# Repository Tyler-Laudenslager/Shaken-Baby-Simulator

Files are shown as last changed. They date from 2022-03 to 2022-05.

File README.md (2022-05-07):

<h1>St. Lukes Simulation Center / The Cauldron</h1>





<h2>Shaken Baby Simulator Project</h2>

<p>.fzz files are from https://fritzing.org/
<br>
.xlsx files are normal Microsoft Excel files
<br>
https://circuitpython.org/
<br>
https://learn.adafruit.com/
<br>
https://codewith.mu/en/
</p>
<br>
<br>
<p>There are no <b>malicious<b> files in this repo!!</p>

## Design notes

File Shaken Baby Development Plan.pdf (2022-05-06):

# Shaken Baby Simulator Software Development Plan & Requirements

March 1, 2022

Version 1.1

Presented To:

St. Luke's Network Simulation Center 3D Print & Innovation Lab

Submitted By:
Tyler Laudenslager, Boyd Lenich, and Andrew Sheidy

### REVISION HISTORY

Date | Author | Distributed to | Version | Description
February 27th | | | 1.0 | Draft
March 1st | Tyler L. | N?A | 1.1 | Added more info to Use Cases, Non Functional Requirements, ,Research Sections, and Project Organization sections.
4/10/2022 | Tyler L. | N?A | 1.2 | Added the prototype architecture pictures to the respective section.

REVISION HISTORY | 2
1. PRODUCT DESCRIPTION | 4
2. PRODUCT REQUIREMENTS | 4
Context Diagram | 4
Personas | 5
User Stories | 5
High Level Use Cases | 6
Use Case Descriptions | 6
3. USER EXPERIENCE WIREFRAMES | 9
4. NON FUNCTIONAL REQUIREMENTS | 9
Other Systems | 9
Security | 10
Performance | 10
Maintainability | 10
Budget | 10
5. PROJECT ORGANIZATION - | 12
Matrix of Responsibilities / Skills | 12
PERT / Gantt Chart | 13
6. VALIDATION PLAN | 13
Test Strategy | 13
7. RISK MANAGEMENT PLAN | 14
Research | 14
Baby Research - Need to Do | 14
Hardware / Software Research | 14
Risk Identification | 17
Risk Prioritization | 17
Risk Mitigation | 17
8. CONFIGURATION AND VERSION CONTROL | 18
9. TOOLS | 18
10. ARCHITECTURE | 19
11. RELATED LINKS | 19

### 1. PRODUCT DESCRIPTION

We are solving an issue with child care, specifically for guardians who are new to interacting with an infant. The idea is to have a doll that responds to how it is treated to show signs of shaken baby syndrome, an issue that can happen if improper care is given while holding an infant. The doll will give info, to tell the handler that they are handling the baby correctly, or if they are giving the doll too much motion, and it will respond with information on a screen, as well as with qualitative changes, such as sound, and color.

### 2. PRODUCT REQUIREMENTS

Describe the users and user environment.

### Context Diagram

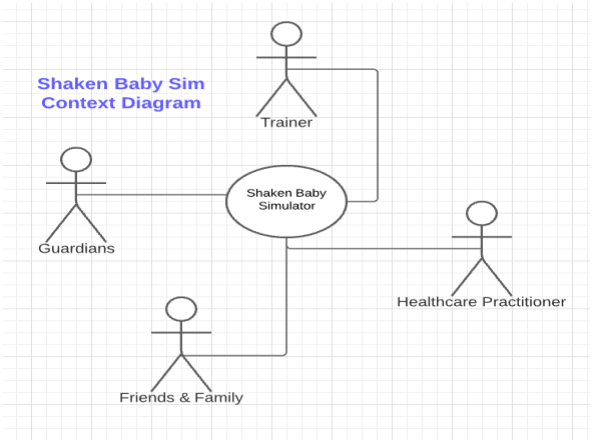
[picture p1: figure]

### Personas

Healthcare practitioner - Someone who would want to use to learn about child handling in a healthcare sense rather than a guardian sense

Family and Friends - Connected to the guardian, but does not need as in depth coaching on child handling as they would not have as close proximity

Guardians - Wants an in depth look on how to handle a child safely

Educator / Trainer - Someone who is using the doll as a teaching tool for others

### User Stories

- Healthcare Practitioner
- As a nurse, I want accurate data representation so I can know more

about child handling at a more detailed level, so I can have more

knowledge when handling a child.

- Family and Friends of the Baby
- Being a friend to new parents I would like to be less anxious about

holding a child for the first time and to assure my new parent friends

that I can hold a child properly to have them feel less anxious about

me holding their child. Some of the fears I have is not properly

supporting a child when holding it or some of the dangers that could

be present that I am unaware of when holding the baby.

- As a grandparent I would like to show my competency in holding a

baby to my children, so they feel less anxious about me handling

fragile packaging.

- As a six-year-old I would like to show everyone that I am capable of

important things such as being able to properly show I am all grown

up to handle a baby now.

- I am a babysitter who would like to train other babysitters how to

properly hold a baby to provide confidence to them and the parents

of the baby before they need to watch the baby.

- Guardians of the Baby
- As a parent, I want to know more about child handling, and how safe

I need to be when handling them so that I can be a better parent.

- As a parent, I want my older children to be able to understand how

fragile a child is so they can safely interact with their new siblings.

- Educator / Trainer
- As an Educator / Trainer, I want to teach parents about child handling

in a way that gives them more information and experience, so that I

can do my job more efficiently and train them better.

### High Level Use Cases

Rotate Baby - rotating the baby in various horizontal and vertical positions.

Shake Baby - shaking the baby gently, moderately, and violently.

Drop Baby - dropping the baby from various heights.

Read Condition - read the condition of the baby (good/dangerous/bad).

### Use Case Descriptions

1. Name: Rotate Baby
2. Participating Actors: Healthcare Practitioner, Trainer, Baby Handler..

3. Entry Condition: Charged Battery.
4. Exit Condition: Baby Makes Sound.
5. Flow of Events:
a. Pick up baby sim.
b. Rotate baby sim.
c. Emit sound/no sound from baby.
6. Special Requirements:
a. If the baby is upside down, have the baby cry until the baby is upright.

—---------------------------------------------------------------------------------------------------

1. Name: Shake Baby
2. Participating Actors: Healthcare Practitioner, Trainer, Baby Handler
3. Entry Condition: Charged Battery
4. Exit Condition: Baby Displays Light from LEDs
5. Flow of Events:
a. Pick up baby sim
b. Shake baby sim
c. Emit light from LEDs
6. Special Requirements:
a. If the baby is shaken at max force level, display red
b. If the baby is shaken at moderate force level, display yellow
c. If the baby is shaken at gentle force level, display green.

—---------------------------------------------------------------------------------------------------

1. Name: Drop Baby
2. Participating Actors: Healthcare Practitioner, Trainer, Guardian, Baby Handler.
3. Entry Condition: Charged Battery.
4. Exit Condition: Baby Cries and Displays Light from LEDs.
5. Flow of Events:
a. Pick up baby sim.
b. Drop baby sim from a relative height.
c. Emit sound.
d. Emit light.
6. Special Requirements:
a. If time to fall is below a half a second display yellow.
b. If time to fall is above half a second display red.

—---------------------------------------------------------------------------------------------------

1. Name: Read Condition
2. Participating Actors: Healthcare Practitioner, Trainer, Baby Handler
3. Entry Condition: Charged Battery and (Shake or Drop or Rotate event)
4. Exit Condition: Condition Understood
5. Flow of Events:
a. Perform either a Rotate or Drop or Shake operation on the baby sim

b. Read the condition
c. Reference the User Manual
d. Understand the condition

### 3. USER EXPERIENCE WIREFRAMES

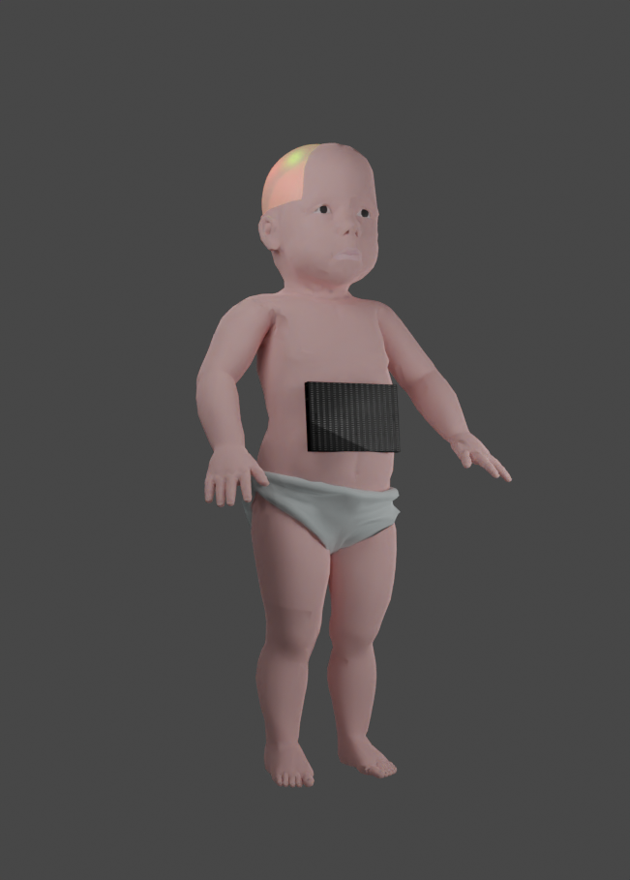
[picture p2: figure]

### 4. NON FUNCTIONAL REQUIREMENTS Other Systems

What other systems to interface with? Dependent on?.

The system is self contained and does not depend on outside systems to operate with full usability.

### Security

There will be an emphasis on protecting end users from any damage that can occur when dealing with any lithium-ion battery packs. There will also be considerations to dealing with making it difficult to accidentally be in direct contact with the system itself. We will provide this functionality by encasing the system within the baby itself.

### Performance

Up time - We are planning on having the system be up and fully usable only when required to be and off when necessary.

Response time? - The response time of the system should be near real time responsiveness with a plus / minus a half second delay.

### Maintainability

How will it be maintained? - The system will be maintained remotely when necessary to incorporate other features requested by the customer using a version control system such as Github with full documentation to provide full disclosure of the changes made to the system over time for the customer and users alike.

### Budget

## Shaken Baby Simulator Prototype Shopping List

Product Page | Description | Price (in dollars $) | Quantit y to Purcha se
https://www.adafruit.com/product/2809 (https://www.adafruit.com/product/2809) | Adafruit LIS3DH Triple-Axis Accelerometer (+-2g/4g/8g/16g) | $4.95 | 1
https://www.adafruit.com/product/4884 (https://www.adafruit.com/product/4884) | Black Adafruit Feather RP2040 | $11.95 | 1
https://www.adafrui (https://www.adafruit.com/product/4864) | Raspberry Pi Pico RP2040 | $4.00 | 1

t.com/product/4864 (https://www.adafruit.com/product/4864)

https://www.adafruit.com/product/2671 (https://www.adafruit.com/product/2671) | 2mm Pitch 40-Pin Break-apart Male Headers -Pack of 5 | $2.95 | 1
https://www.adafruit.com/product/159 (https://www.adafruit.com/product/159) | Diffused RGB (tri-color) LED - Common Anode | $6.00 | 3
https://www.adafruit.com/product/3006 (https://www.adafruit.com/product/3006) | Adafruit I2S 3W Class D Amplifier Breakout -MAX98357A | $5.95 | 1
https://www.adafruit.com/product/3968 (https://www.adafruit.com/product/3968) | Speaker - 40mm Diameter -4 Ohm 3 Watt | $4.95 | 1
https://www.adafruit.com/product/258 (https://www.adafruit.com/product/258) | Lithium Ion Polymer Battery - 3.7v 1200mAh | $9.95 | 1
https://www.adafruit.com/product/1954 (https://www.adafruit.com/product/1954) | Premium Female/Male 'Extension' Jumper Wires -20 x 6" | $1.95 | 1
https://www.adafruit.com/product/902 (https://www.adafruit.com/product/902) | Adafruit Bicolor LED Square Pixel Matrix with I2C Backpack | $15.95
| Price Total | $68.60
| Optional Choices | | 1
https://www.adafruit.com/product/2738 (https://www.adafruit.com/product/2738) | Raspberry Pi Sense HAT -any Raspberry Pi with 2x20 Connector | $39.95

*Some products may be discontinued and / or unavailable due to supply shortages / demand.

**Prices subject to change.

### 5. PROJECT ORGANIZATION -

Breakdown of major tasks and schedule

Key

NC - Not Comfortable

C - Comfortable

P - Partial Experience

### Matrix of Responsibilities / Skills

Skills Needed | Skills Acquired
| Drew S. | Boyd L. | Tyler L.
Circuit Python | NC
Github / Git | P | P | P
User Interface | P | | P
Product Design | P | | P
Baby Research | P | P
Knowledge of Microcontrollers | NC
Knowledge of Accelerometers | NC
Knowledge of Speakers | NC
Two-Dimensional Array Programming | NC | P | P
Debugging / Troubleshooting | P P

Skills Needed | Skills Acquired
Testing | P | P
Responsibilities | Drew S. | Boyd L. | Tyler L.
Testing | P
Anatomical Research | NC | X
LED Matrix Programming | NC | | X
Accelerometer Programming | NC | X | X
Hardware Research | P X
User Interface Design | p | x
Circuitry Design | NC | | X

### PERT / Gantt Chart

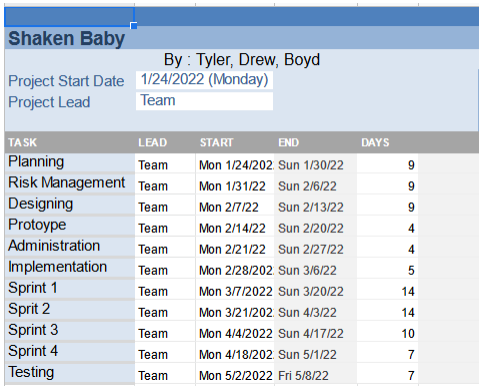
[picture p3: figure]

### 6. VALIDATION PLAN

### Test Strategy

What is the definition of done?

The definition of done is defined as all components have been integrated together within the system and the system has been fully tested for each expected input output of every use case.

What does success look like?

Success is the measure of how effectively we convey to the user of the system how to properly handle a baby given the force applied in various situations using clearly defined indicators built into the system.

If the user can instantly tell when they have applied too much force to the baby in any given situation this is how we will know we have achieved success.

### 7. RISK MANAGEMENT PLAN

What are the known risks and how will they be handled?

### Research

Hardware / Software Research

In this part we are going to discuss all the hardware decisions as related to the design of the shaken baby simulator. We will discuss the differences between a microcontroller versus a micro-computer. After a brief discussion we will discuss all the major components of the system and why we decided to choose some components over others. We will conclude with a brief discussion of the software that is needed to control the hardware of the system.

Microcontroller Vs. Micro-Computer:

There is a distinct reason we used a Micro-Controller such as an Arduino versus a Micro-Computer such as a Raspberry Pi in this implementation of the system. A Micro-Controller has a dedicated program that runs in a loop that provides a specific functionality and is very suitable for connecting various components such as temperature, acceleration and light sensors and emitters. A Micro-Computer is more for variable uses across a variety of different applications depending on the needs of the user at a particular time.

With the previous discussion in mind therefore we decided to choose a Microcontroller instead of a Micro-Computer for the project implementation. The specific Micro-Controller that we chose was a decision that was based on a few aspects of the project such as availability of hardware due to the on-going chip storage as well as the cost of the Microcontroller as well as the API (Application Programmer Interface) to interface with the various sensor components we needed to develop the project well. We ended up choosing the Adafruit Feather RP2040 for a few reasons over other variations. First is that we needed to have a battery connected to the Microcontroller that was housed inside the baby simulator. The second is that the Feather RP2040 supports built-in charger regulation using USB-C which is becoming the standard in charging ports on various devices. The third is that it has plenty of GPIO ports to interface with various components using Circuit Python.

Hardware Decisions:

There are a few main components to the project that will be described in detail here. We will also describe a few advantages that we can leverage by choosing these specific components. The main system is built by having an accelerometer connected to a feather RP2040 which is also connected to a 8x8 pixel grid plus a speaker and led light for sound/light respectively. The reason we chose the feather RP2040 instead of another microcontroller is due to the ease of use in connecting various other components needed for the project using Circuit Python libraries which are controlled using the Python programming language. Also the Feather RP2040 has the Raspberry PI 2040 processor chip which has PIO ports (Programmable Input Output) . These ports allow you to write software to interface properly with all kinds of different components that we would otherwise not be able to do. Everytime the feather RP2040 is powered on by either a dedicated power source such as a USB-C charging cable or a portable lithium ion battery pack the script that is saved runs automatically and nearly instantaneously. The 8x8 led grid we have chosen perfectly displays all three of the colors we wanted to show: green, red, yellow. These colors correspond to the various levels of danger with green being the least worrying to red being the most force being applied to the simulator. The backpack that attaches to the 8x8 led grid is necessary to interface with the 8x8 grid with only four wires instead of sixteen. This reduces the amount of wiring in the project. We went with a speaker that was not going to break with extended use of the system instead of getting a fragile speaker for cheaper.

Software API Overview:

The main component to programming the project comes from the various libraries provided by the Circuit Python framework which allows you to interface with various components using a lot of microcontrollers by simply programming in a relatively familiar and known programming language Python. The documentation can be found here at this website https://circuitpython.org/.

The getting started with Circuit Python page can be found here: https://learn.adafruit.com/welcome-to-circuitpython/circuitpython-libraries.

The overview of the feather RP2040 can be found here as well:

https://learn.adafruit.com/adafruit-feather-rp2040-pico.

### Risk Identification

The biggest risk is an accurate range of force to damage reading, measuring force accurately on a doll can be difficult with the tools we have available.

Competition, being able to be a viable counterpart to the other shaken baby simulator we found is important

Making sure the doll is able to go through testing and last, with both battery, and being able to last without damage

### Risk Prioritization

Prioritized list (biggest risk -> lowest risk)

1. Accuracy
2. Damage Possibility
3. Battery
4. Competition

### Risk Mitigation

1.Accuracy: Can be mitigated by thorough testing and research. Testing can help us dial in measurements and ensure that the data collected is accurate, and research can ensure we know the ranges of force that the doll should respond to.

2.Damage: This can be mitigated by testing different actions and force on the doll and seeing how the technical components handle it, we can work through designs and different measure to ensure that the doll can survive the force needed to test, such as other accidental damages such as dropping.

3.Battery: This should not be an issue, as batteries in general can last a long time, but this should still be a general consideration for the doll, as having a long battery life will be important for medical demonstrations and training sessions

4.Competition: We can research competition to come up with ways to differentiate in both price and features to insure that our doll stands apart from other competitors that currently exist.

### 8. CONFIGURATION AND VERSION CONTROL

Github will be used for configuration and version control.

www.github.com

### 9. TOOLS

Mu - Python Text Edition -> https://codewith.mu/

Must Have (This is due to the full writes when saving as explained further here : https://learn.adafruit.com/welcome-to-circuitpython/recommended-editors)

Github (Software Version Control / Project Management) -> https://github.com/

Circuit Python -> https://circuitpython.org/

Adafruit Learn -> https://learn.adafruit.com/

Fritzing Circuit Builder -> https://fritzing.org/

### 10. ARCHITECTURE

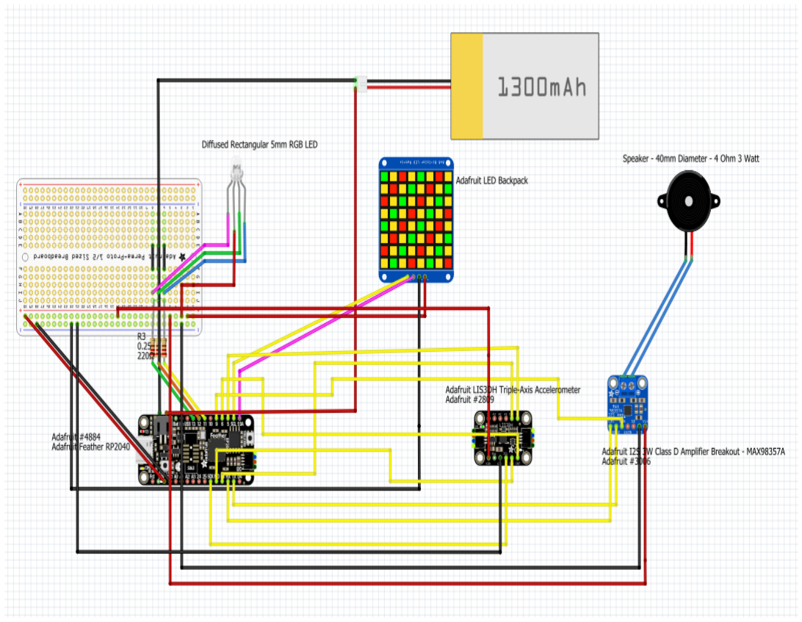
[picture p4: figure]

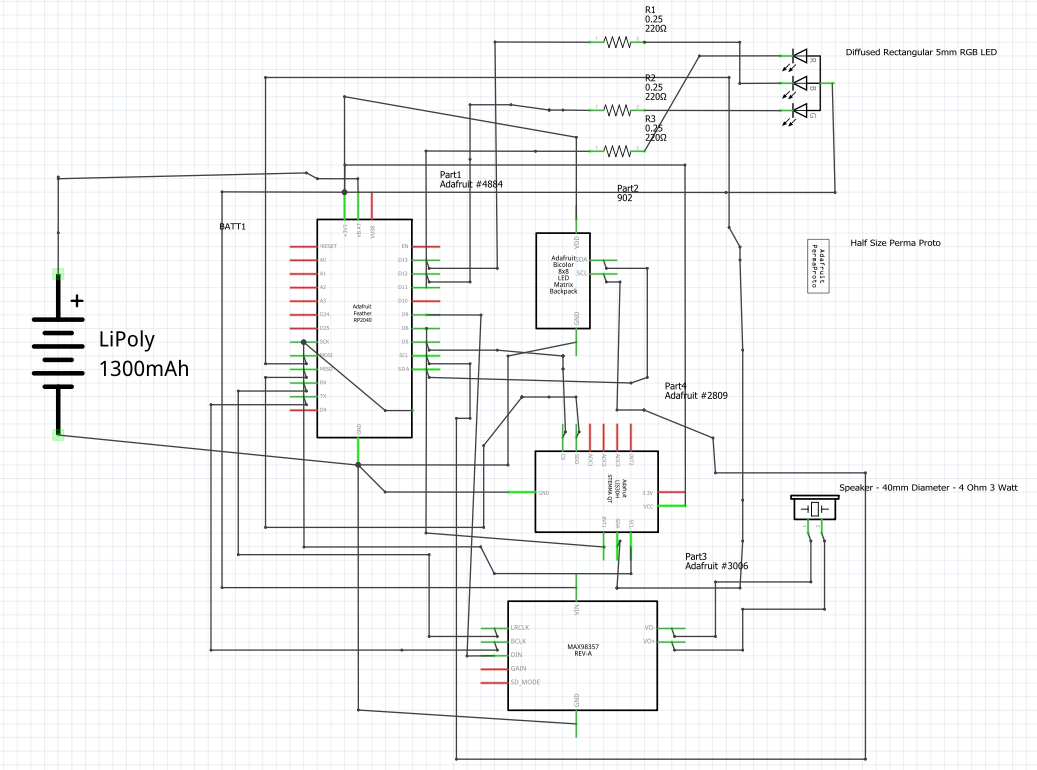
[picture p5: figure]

### 11. RELATED LINKS

https://codewith.mu/

https://learn.adafruit.com/welcome-to-circuitpython

https://learn.adafruit.com/adafruit-feather-rp2040-pico

https://learn.adafruit.com/adafruit-lis3dh-triple-axis-accelerometer-breakout

https://learn.adafruit.com/adafruit-led-backpack/1-2-8x8-matrix

https://projects.raspberrypi.org/en

https://www.recantha.co.uk/blog/?p=20950

https://fritzing.org/

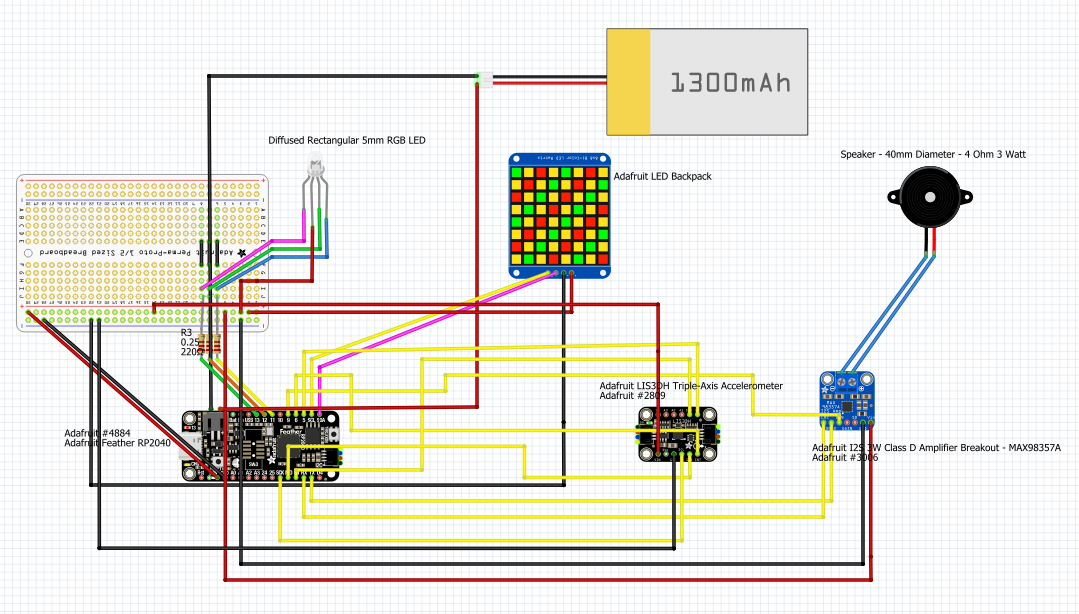
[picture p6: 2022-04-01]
shaken_baby_breadboard_schematic.png

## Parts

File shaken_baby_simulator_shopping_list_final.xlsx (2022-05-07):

Shaken Baby Simulator Shopping List
Product Page | Description | Price (in dollars $) | Quantity to Purchase
https://www.adafruit.com/product/2809 | Adafruit LIS3DH Triple-Axis Accelerometer (+-2g/4g/8g/16g) | $4.95 | 1
https://www.adafruit.com/product/4884 | Black Adafruit Feather RP2040 | $11.95 | 1
https://www.adafruit.com/product/3006 | Adafruit I2S 3W Class D Amplifier Breakout - MAX98357A | $5.95 | 1
https://www.adafruit.com/product/3968 | Speaker - 40mm Diameter - 4 Ohm 3 Watt | $4.95 | 1
https://www.adafruit.com/product/3898 | Lithium Ion Polymer Battery Ideal For Feathers - 3.7V 400mAh | $6.95 | 1
https://www.adafruit.com/product/1954 | Premium Female/Male 'Extension' Jumper Wires - 20 x 6" | $1.95 | 1
https://www.adafruit.com/product/902 | Adafruit Bicolor LED Square Pixel Matrix with I2C Backpack | $15.95 | 1
https://www.adafruit.com/product/3064 | JST 2-pin Extension Cable with On/Off Switch - JST PH2 | $2.95 | 1
https://www.adafruit.com/product/2739 | Diffused Rectangular 5mm RGB LEDs | $5.95 | 1
https://www.adafruit.com/product/1957 | Premium Male/Male Jumper Wires - 20 x 6" (150mm) | $1.95 | 1
https://www.adafruit.com/product/2780 | Through-Hole Resistors - 220 ohm 5% 1/4W - Pack of 25 | $0.75 | 1
https://www.amazon.com/dp/B07WH13G67?ref=ppx_yo2ov_dt_b_product_details&th=1 | USB Type C Extension Adapter 3-Pack | $7.99 | 1
https://www.amazon.com/GE-Sealants-Adhesives-Silicone-GE361A/dp/B089N98MBT | GE Sealants & Adhesives Silicone | $3.15 | 1
https://www.amazon.com/XHF-Inch-13mm-Waterproof-Insulation/dp/B07FPDBGYH?ref_=ast_slp_dp&th=1 | Waterproof Heat Shrink Tubing Marine Grade | $5.69 | 1
 | Price Total | $81.08

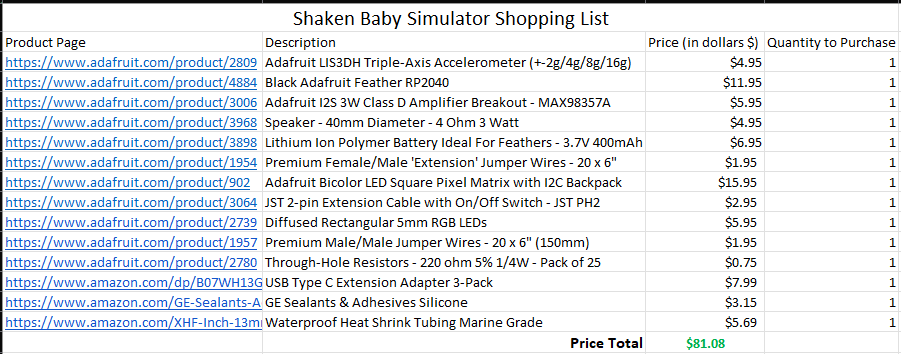
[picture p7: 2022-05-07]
shaken_baby_shopping_list.png

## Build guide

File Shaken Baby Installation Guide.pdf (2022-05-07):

# Installation Guide

Shaken Baby Simulator

## Recommended Educational Prerequisites

- The recommended formal education for a thorough understanding of the project described within these slides is listed as follows.
- Extensive Knowledge in Computer Science / Computer Engineering
- Pulse Width Modulation
- General Purpose Electronic Prototyping / Electronic Engineering
- Formal Software Requirements Specification Training / Project Analysis
- Intermediate Circuit Python Programming Experience
- RP2040 PIO Assembly Language Expertise
- Ohm’s Law
- Amdahl’s Law
- Pareto’s Principle

## Tools Used

## - Adafruit Learn -https://learn.adafruit.com/guides/beginner - Mu Text Editor -https://codewith.mu/en/download - Python 3- https://docs.python.org/3/ - Circuit Python - https://circuitpython.org/

## Required Parts

- Adafruit #4884 – Adafruit Feather RP2040
- https://www.adafruit.com/product/4884
- Adafruit LIS3DH Triple-Axis Accelerometer (+-2g/4g/8g/16g)
- https://www.adafruit.com/product/2809
- Adafruit Bicolor LED Square Pixel Matrix with I2C Backpack
- https://www.adafruit.com/product/902
- Adafruit I2S 3W Class D Amplifier Breakout - MAX98357A
- https://www.adafruit.com/product/3006

## Required Parts

- Lithium Ion Polymer Battery - 3.7v 400mAh
- https://www.adafruit.com/product/258
- Speaker - 40mm Diameter - 4 Ohm 3 Watt
- https://www.adafruit.com/product/3968

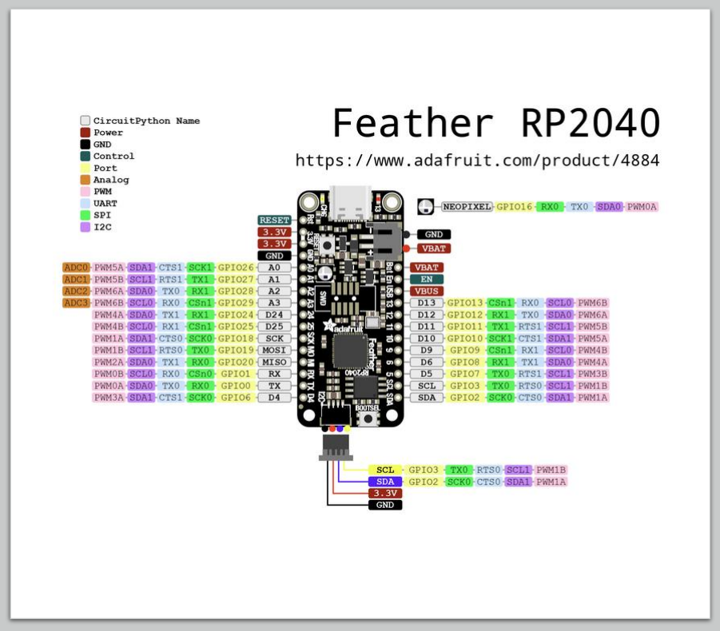
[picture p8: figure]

## Feather RP2040 Setup Guide

- https://learn.adafruit.com/ad afruit-feather-rp2040-pico (https://learn.adafruit.com/adafruit-feather-rp2040-pico)
- Plug Device In to Computer
- Using cable that supports data / charging
- Follow this guide next
- https://learn.adafruit.com/ad afruit-feather-rp2040-
pico/circuitpython (https://learn.adafruit.com/adafruit-feather-rp2040-pico/circuitpython)

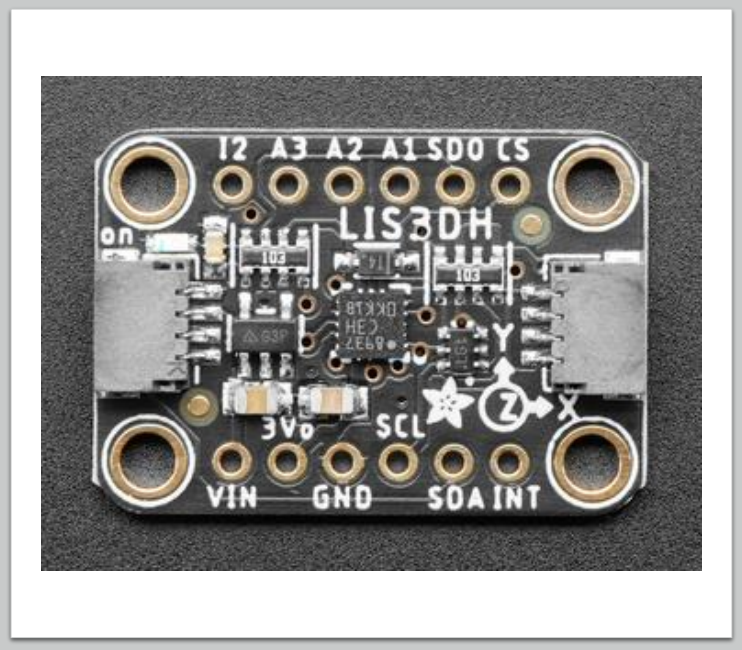
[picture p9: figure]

## Accelerometer Guide

- Assembly
- https://learn.adafruit.com/ada fruit-lis3dh-triple-axisaccelerometerbreakout/assembly (https://learn.adafruit.com/adafruit-lis3dh-triple-axis-accelerometer-breakout/assembly)
- Programming
- https://learn.adafruit.com/ada fruit-lis3dh-triple-axisaccelerometerbreakout/python-circuitpython (https://learn.adafruit.com/adafruit-lis3dh-triple-axis-accelerometer-breakout/python-circuitpython)

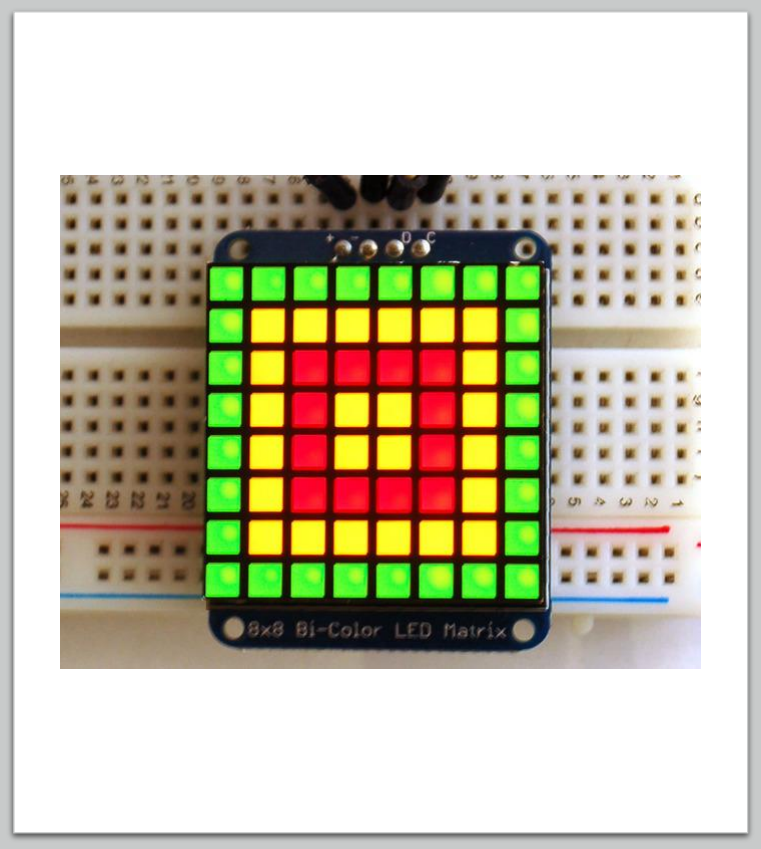
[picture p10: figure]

## Adafruit Bicolor LED Square Pixel Matrix with I2C Backpack

- https://learn.adafruit.com/adafruitled-backpack/bi-color-8x8-matrixassembly - (DON’T INSTALL (https://learn.adafruit.com/adafruit-led-backpack/bi-color-8x8-matrix-assembly)
INCORRECTLY)
- https://learn.adafruit.com/adafruitled-backpack/bi-color-8x8-matrixcircuitpython-wiring-and-setup (https://learn.adafruit.com/adafruit-led-backpack/bi-color-8x8-matrix-circuitpython-wiring-and-setup)
- https://learn.adafruit.com/adafruitled-backpack/bi-color-8x8-matrixcircuitpython-and-python-usage (https://learn.adafruit.com/adafruit-led-backpack/bi-color-8x8-matrix-circuitpython-and-python-usage)

## Follow the Schematic Provided

## - The electronic schematic provides detailed instruction of how the circuit should be

assembled.

## - Various electronic debugging may be

necessary.

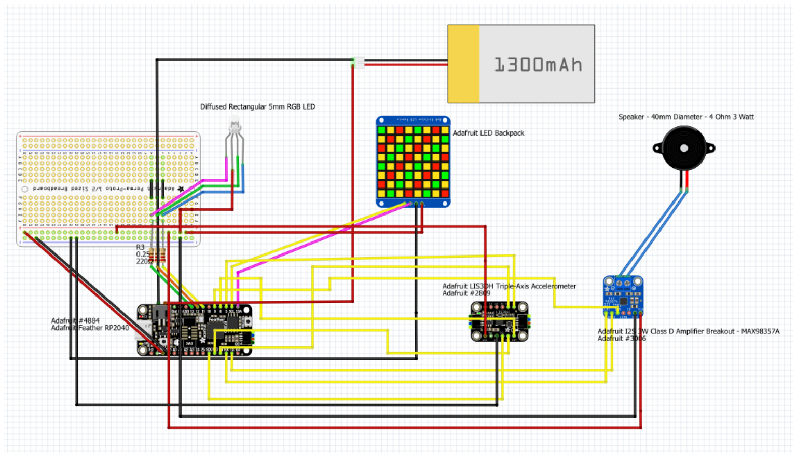
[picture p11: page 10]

## Install the RGB LEDs

- Learn about PWM (Pulse Width Modulation).
- Install six RGB LEDs in parallel configuration within the schematic used in the previous instruction slide.
- Drill 6 holes ¼ inch wide into the silicone brain.
- Insert each RGB LED in the following configuration.
- 2 in the front.
- 2 on the sides, one on each side.
- 2 in the back.

## Combine Components

### Assemble all the components together and load the prototype_final_code_with_RGB_LED code into the

RP2040.

### Disassemble doll, remove padding inside and put all

the components within the doll.

## Need Help?

## - Join the Discord Adafruit server for any questions related to electronic debugging and

configuration.
- Utilize various online maker blogs and tutorials.

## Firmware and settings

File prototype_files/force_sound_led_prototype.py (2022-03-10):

import board
import time
import random
import digitalio
import audiocore
import audiobusio
import adafruit_lis3dh
from adafruit_ht16k33.matrix import Matrix8x8x2

#setup for 3 color matrix
i2c = board.I2C()
matrix = Matrix8x8x2(i2c)
#end setup

#setup for accelerometer
spi = board.SPI()
cs = digitalio.DigitalInOut(board.D5)  # Set to appropriate CS pin!
int1 = digitalio.DigitalInOut(board.D6) # Set to correct pin for interrupt!
lis3dh = adafruit_lis3dh.LIS3DH_SPI(spi, cs, int1=int1)
#end setup

#audio setup
f = open("StreetChicken.wav", "rb")
wav = audiocore.WaveFile(f)
i2s = audiobusio.I2SOut(board.D1, board.D0, board.D9)

#erase colors from board
matrix.fill(0)


def light_column(matrix, column, color):
    for position in range(0,8):
        matrix[position, column] = color

def light_board(matrix, display_force):
    actual_size = display_force-1
    if actual_size >= 0:
        light_column(matrix, 0, color=matrix.LED_GREEN)
    if actual_size >= 1:
        light_column(matrix, 1, color=matrix.LED_GREEN)
    if actual_size >= 2:
        light_column(matrix, 2, color=matrix.LED_YELLOW)
    if actual_size >= 3:
        light_column(matrix, 3, color=matrix.LED_YELLOW)
    if actual_size >= 4:
        light_column(matrix, 4, color=matrix.LED_YELLOW)
    if actual_size >= 5:
        light_column(matrix, 5, color=matrix.LED_RED)
    if actual_size >= 6:
        light_column(matrix, 6, color=matrix.LED_RED)
    if actual_size == 7:
        light_column(matrix, 7, color=matrix.LED_RED)

def read_force_from_accelerometer(matrix):
    force_read = 1
    if lis3dh.shake(shake_threshold=15):
        force_read = 8
        print("force", force_read)
    elif lis3dh.shake(shake_threshold=12):
        force_read = 6
        print("force", force_read)
    elif lis3dh.shake(shake_threshold=10):
        force_read = 4
        print("force", force_read)
    elif lis3dh.shake(shake_threshold=5):
        force_read = 1
        print("force", force_read)

    light_board(matrix, display_force=force_read)
    time.sleep(0.1)
    matrix.fill(0)


while True:
    start=time.monotonic()
    i2s.play(wav)
    while i2s.playing:
        read_force_from_accelerometer(matrix)
    stop = time.monotonic()
    print("Total lenght = ", stop, "-", start, "=", stop-start)

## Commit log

2022-03-22 Create prototype_final_code
2022-03-28 Create prototype_final_code_with_RGB_LED
